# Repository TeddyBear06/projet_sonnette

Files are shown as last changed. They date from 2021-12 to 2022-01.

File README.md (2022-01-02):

# DIY sonnette

First, if you want to see the result, have a look at [this video](https://youtu.be/OrXuBeXwijw).

## Requirements

- 2 x [Elegoo nano](https://www.elegoo.com/products/elegoo-nano-v3-0)
- 2 x [E32-868T20D](https://www.ebyte.com/en/product-view-news.aspx?id=132)
- 4 x 18650 battery
- 2 x 18650 battery holder (7.4v)
- 2 x [Speaker](https://wiki.seeedstudio.com/Grove-Speaker/)
- 1 x Push button (Adafruit
- 1 x 220ohm resistance

NB: Regarding local regulations, you perhaps need something different that 868mHz (maybe 433mHz), please respect local regulations. I'm not responsible if you use a forbidden frequency in your country.

# Arduino IDE configuration

- Card: Arduino nano
- Processor: Atmega328P
- Programmator: AVRISP mkll

# Code

Have a look inside the repo's code folder, or access directly [sender code](code/sender/sender.ino) or [receiver code](code/receiver/receiver.ino).

# Schemas

## Sender

When someone push the button, a message will be displayed on the OLED screen (for instance, "Appel en cours..." but you can modify it in the source code). Then the - builtin - LED will start blinking until the end of the pause time (only one message is sent to the receiver to save batteries). Once it's done, the screen is switched off and someone can push the button again.

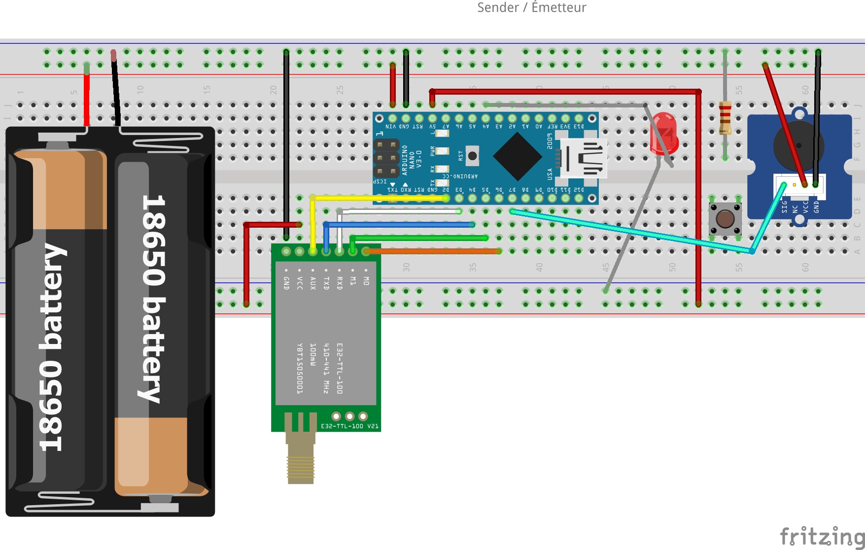
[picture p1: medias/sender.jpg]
Sender


## Receiver

When the receiver catch a message, it will look at its value and if it's the expected one (see this as a binding process) it will start ringing 4 times then stop and swith back to listening mode again.

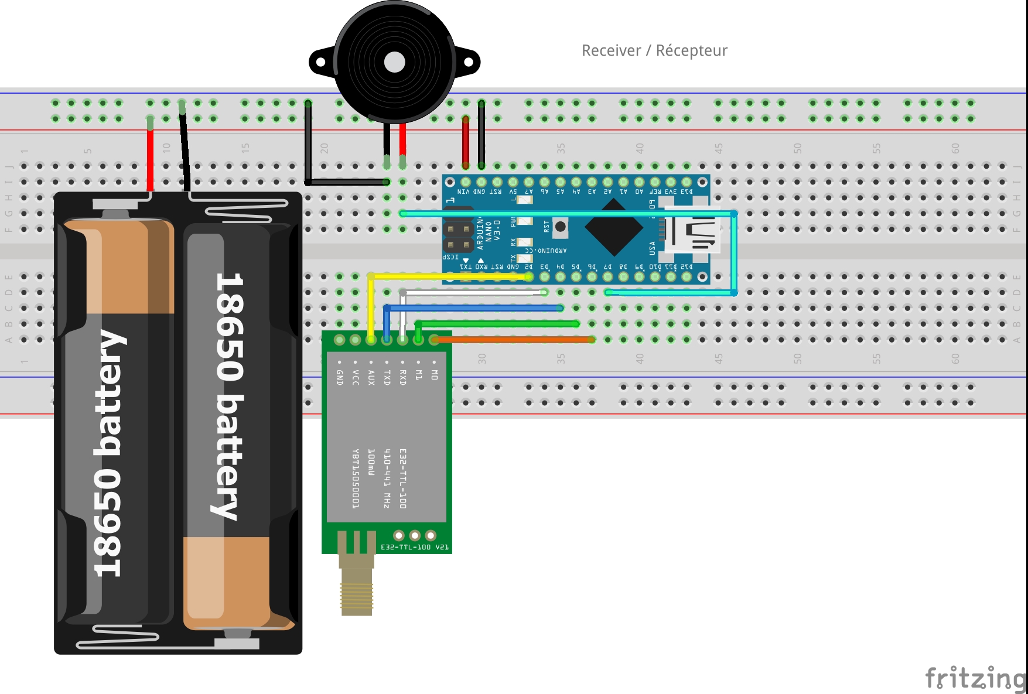
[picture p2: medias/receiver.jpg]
Receiver


# Thanks

- [Kris Kasprzak](https://github.com/KrisKasprzak/EBYTE) for the usefull Ebyte lib;
- [Fritzing](https://fritzing.org/) for making shemas production easier;
- Fritzing community for building custom modules that we can import and use in our schemas.

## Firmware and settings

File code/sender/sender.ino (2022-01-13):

#include <SoftwareSerial.h>
#include "EBYTE.h"

#define PIN_AX  2
#define PIN_TX  4
#define PIN_RX  3
#define PIN_M1  5
#define PIN_M0  6
#define BTN     A5
#define LED_BTN A4
#define SPK     7
#define VOLT_INPUT A0
#define LED_VERTE A1
#define LED_ORANG A2
#define LED_ROUGE A3

struct DATA {
  int State;
};

DATA Message;

SoftwareSerial ESerial(PIN_RX, PIN_TX);
EBYTE Transceiver(&ESerial, PIN_M0, PIN_M1, PIN_AX);

void setup() {
  ESerial.begin(9600);
  pinMode(LED_BUILTIN, OUTPUT);
  pinMode(BTN, INPUT_PULLUP);
  pinMode(LED_BTN, OUTPUT);
  digitalWrite(LED_BTN, LOW);
  pinMode(SPK, OUTPUT);
  digitalWrite(SPK, LOW);
  pinMode(LED_VERTE, OUTPUT);
  pinMode(LED_ORANG, OUTPUT);
  pinMode(LED_ROUGE, OUTPUT);
  Transceiver.init();
}

void loop() {
  checkVoltage();
  if (digitalRead(BTN) == HIGH){
    Message.State = 1;
    Transceiver.SendStruct(&Message, sizeof(Message));
    for (int j=0;j<3;j++) {
      digitalWrite(LED_BTN, HIGH);
      ringTheBell();
      digitalWrite(LED_BTN, LOW);
      delay(1000);
    }
  } else {
    digitalWrite(LED_BTN, LOW);
  }
}

void checkVoltage() {
  int raw_volt_input_val;
  int input_voltage;
  float temp;
  raw_volt_input_val = analogRead(VOLT_INPUT);
  temp = (raw_volt_input_val * 7) / 1024.0;
  input_voltage = temp / (7500.0/(30000.0+7500.0));
  if (input_voltage < 4) {
    digitalWrite(LED_VERTE, LOW);
    digitalWrite(LED_ORANG, LOW);
    digitalWrite(LED_ROUGE, HIGH);
  } else if (input_voltage >= 4 && input_voltage <= 5) {
    digitalWrite(LED_VERTE, LOW);
    digitalWrite(LED_ORANG, HIGH);
    digitalWrite(LED_ROUGE, LOW);
  } else {
    digitalWrite(LED_VERTE, HIGH);
    digitalWrite(LED_ORANG, LOW);
    digitalWrite(LED_ROUGE, LOW);
  }
}

void ringTheBell() {
  tone(SPK, 2500, 1000);
  delay(1000);
  tone(SPK, 1000, 2000);
  delay(2000);
  digitalWrite(SPK, LOW);
}

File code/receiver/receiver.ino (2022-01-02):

#include <SoftwareSerial.h>
#include "EBYTE.h"

#define PIN_AX 2
#define PIN_TX 4
#define PIN_RX 3
#define PIN_M1 5
#define PIN_M0 6
#define SPK    7

struct DATA {
  int State;
};

DATA Message;
unsigned long Last;

SoftwareSerial ESerial(PIN_RX, PIN_TX);
EBYTE Transceiver(&ESerial, PIN_M0, PIN_M1, PIN_AX);

void setup() {
  ESerial.begin(9600);
  pinMode(LED_BUILTIN, OUTPUT);
  digitalWrite(LED_BUILTIN, LOW);
  pinMode(SPK, OUTPUT);
  digitalWrite(SPK, LOW);
  Transceiver.init();
}

void loop() {
  if (Transceiver.available()) {
    Transceiver.GetStruct(&Message, sizeof(Message));
    if (Message.State == 1) {
      for (int i = 0; i < 3; i++) {
        digitalWrite(LED_BUILTIN, HIGH);
        ringTheBell();
        digitalWrite(LED_BUILTIN, LOW);
        delay(1000);
      }
    } else {
      digitalWrite(LED_BUILTIN, LOW);
    }
    Last = millis();
  } else {
    digitalWrite(LED_BUILTIN, LOW);
    if ((millis() - Last) > 1000) {
      Last = millis();
    }
  }
}

void ringTheBell() {
  tone(SPK, 2500, 1000);
  delay(1000);
  tone(SPK, 1000, 2000);
  delay(2000);
  digitalWrite(SPK, LOW);
}

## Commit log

2021-12-14 Initial working version
    [receiver.fzz, sender.fzz]
2021-12-15 Update schema with OLED support
    [sender.fzz]
2021-12-15 Move code to follow Arduino IDE rules
